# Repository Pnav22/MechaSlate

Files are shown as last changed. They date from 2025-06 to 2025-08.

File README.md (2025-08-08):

# MechaSlate 
**A Custom-Built Mechanical Keyboard**  
by Pranav M

---


## Overview
**MechaSlate** is my first custom mechanical keyboard project, created from scratch with no prior experience. This build taught me PCB design using KiCad, CAD modeling with Fusion 360, and the use of plugins and scripts to place keyswitches

[Watch on YouTube](https://www.youtube.com/shorts/u8ZRRqsj9ko)

I wanted to make this project so I could learn more about electronics and familiarize myself with more forms of engineering. It was really fun!
---


####  Initial Layout Planning
I decided on I wanted to make a keyboard like this 
Layout

#### PCB Design

| Schematic |  PCB |
|:--:|:--:|
| Schematics | Wiring |

#### Case Design 
Back and front case modeled for print.

| Back | Front |
|:--:|:--:|
| | Front |

Added a staggering Slot pattern for the back!

####  Final Case
Manually placed all keycaps and installed everything.



---

#### Assembly 

It uses **threaded heat-set inserts (M3 x 5mm x 4mm)** for secure mounting. These inserts are installed into the case.

The top and bottom halves of the keyboard are fastened together using **four M3 x 16mm socket head cap screws .


This project has a Gasket Mount 


| Item Name | Item Source | Quantity | Cost (USD w/ shipping) | Link |
|---|---|---|---|---|
| [Akko V3 Creamy Blue](https://www.amazon.com/Keyboard-Switch-Dustproof-Mechanical-Tactile-Switches/dp/B0C3H7PR1Z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) | Amazon | 80 | $30.98 | ✔️ |
| [PCB x5 (min quantity)]() | JLCPCB | – | $35.00 | ✔️ |
| [1N4148 Diodes](https://www.amazon.com/120Pcs-Rectifier-100Volt-Electronic-Silicon/dp/B0DN62QFYS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) | Amazon | 80 | $5.00 | ✔️ |
| [Durock V3 Stabilizers](https://www.amazon.com/DUROCK-Stabilizer-Innovative-Pre-clipped-Stabilizers/dp/B0CTHNZWN5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) | Amazon | 8 | $15.00 | ✔️ |
| [Heatset Inserts](https://www.amazon.com/Threaded-Inserts-Soldering-Printed-Materials/dp/B0D7M3LJDL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) | Amazon | 4 | $7.00 | ✔️ |
| [Nice_Nano_V2](https://www.amazon.com/AITRIP-Development-Bluetooth-Management-Module%EF%BC%8CNano/dp/B0DCZJKYL1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) | Amazon | 1 | $15.00 | ✔️ |
| [Keycaps](https://www.amazon.com/Keycaps-Doubleshot-Percent-Mechanical-Keyboard/dp/B0D1QVD55F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) | Amazon | 80 | $18.00 | ✔️ |

**Total Cost:** **$125.98**

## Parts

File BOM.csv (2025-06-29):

Bill of Materials / MechaSlate
Pranav Mukkara
6/25/25
Item Name | Item Source | Quantity | cost USD(w/ shipping) | Link
Akko V3 Creamy Blue | Amazon | 80 | 30.98 | https://www.amazon.com/Keyboard-Switch-Dustproof-Mechanical-Tactile-Switches/dp/B0C3H7PR1Z
PCB x5 (min quantity) | PCB WAY |  | 70
1N4148 Diodes | Amazon | 80 | 5 | https://www.amazon.com/120Pcs-Rectifier-100Volt-Electronic-Silicon/dp/B0DN62QFYS
Durock V3 Stabilizers | Amazon | 8 | 15 | https://www.amazon.com/DUROCK-Stabilizer-Innovative-Pre-clipped-Stabilizers/dp/B0CTHNZWN5
heatset inserts | Amazon | 4 | 7 | https://www.amazon.com/Threaded-Inserts-Soldering-Printed-Materials/dp/B0D7M3LJDL
Nice_Nano_V2 | Amazon | 1 | 15 | https://www.amazon.com/AITRIP-Development-Bluetooth-Management-Module%EF%BC%8CNano/dp/B0DCZJKYL1
keycaps | Amazon | 80 | 18 | https://www.amazon.com/Keycaps-Doubleshot-Percent-Mechanical-Keyboard/dp/B0D1QVD55F
Total: |  |  | 160.98

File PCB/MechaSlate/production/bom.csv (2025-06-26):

Designator | Footprint | Quantity | Value | LCSC Part #
D1, D10, D11, D12, D13, D14, D15, D16, D17, D18, D19, D2, D20, D21, D22, D23, D24, D25, D26, D27, D28, D29, D3, D30, D31, D32, D33, D34, D35, D36, D37, D38, D39, D4, D40, D41, D42, D43, D44, D45, D46, D47, D48, D49, D5, D50, D51, D52, D53, D54, D55, D56, D57, D58, D59, D6, D60, D61, D62, D63, D64, D65, D66, D67, D68, D69, D7, D70, D71, D72, D73, D74, D75, D76, D77, D78, D8, D9 | Diode_DO-35 | 78 | Diode
S1, S10, S11, S12, S13, S14, S15, S16, S17, S18, S19, S2, S20, S21, S22, S23, S24, S25, S26, S27, S28, S29, S3, S30, S31, S32, S33, S34, S35, S36, S37, S38, S39, S4, S40, S41, S42, S43, S44, S45, S46, S47, S48, S49, S5, S50, S51, S52, S53, S54, S55, S56, S57, S58, S59, S6, S60, S61, S62, S63, S64, S65, S66, S67, S68, S69, S7, S70, S71, S72, S73, S74, S75, S76, S77, S78, S8, S9 | SW_Cherry_MX_1.00u_PCB | 78 | Keyswitch
U2 | Nice_Nano_V2 | 1 | Nice_Nano_V2

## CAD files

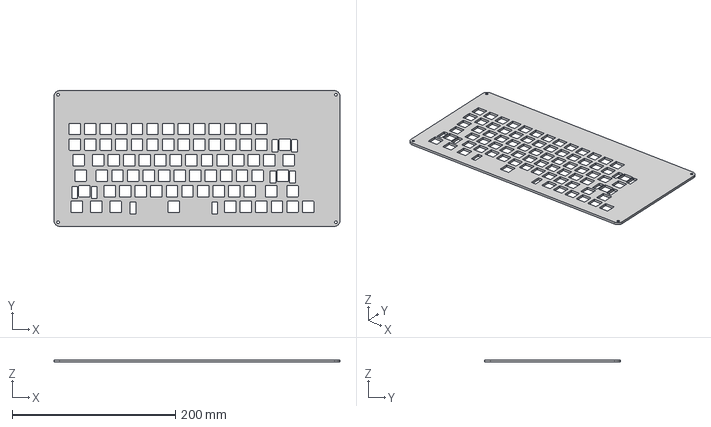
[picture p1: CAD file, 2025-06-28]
CAD/MIDDLE v4.step
350.2 x 166.2 x 3.00 mm

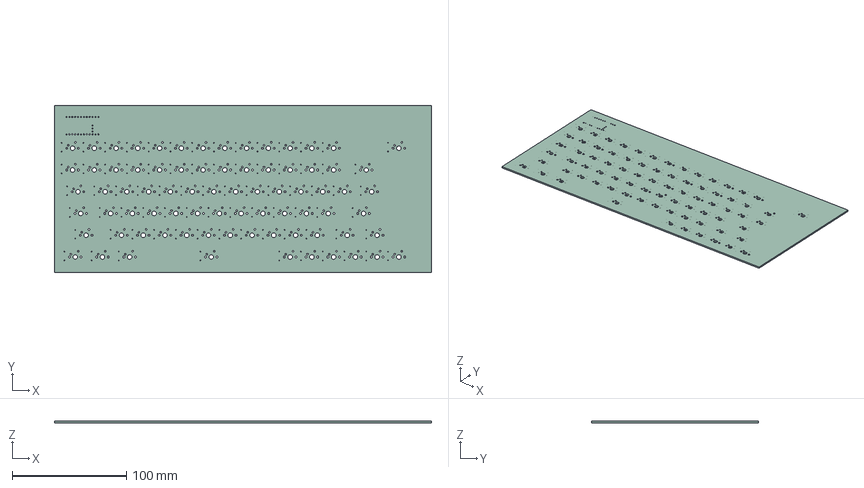
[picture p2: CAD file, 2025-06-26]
PCB/MechaSlate/MechaSlate.step
330.1 x 146.2 x 1.51 mm

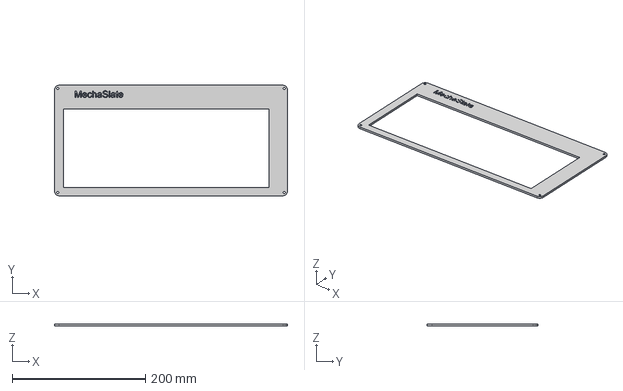
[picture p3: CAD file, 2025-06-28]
CAD/Top v6.step
350.2 x 166.2 x 3.00 mm

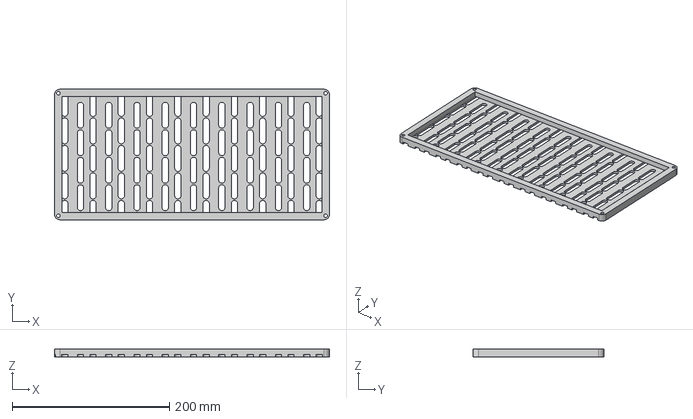
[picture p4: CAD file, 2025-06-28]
Production/Bottom v7.step
350.1 x 166.2 x 10.0 mm

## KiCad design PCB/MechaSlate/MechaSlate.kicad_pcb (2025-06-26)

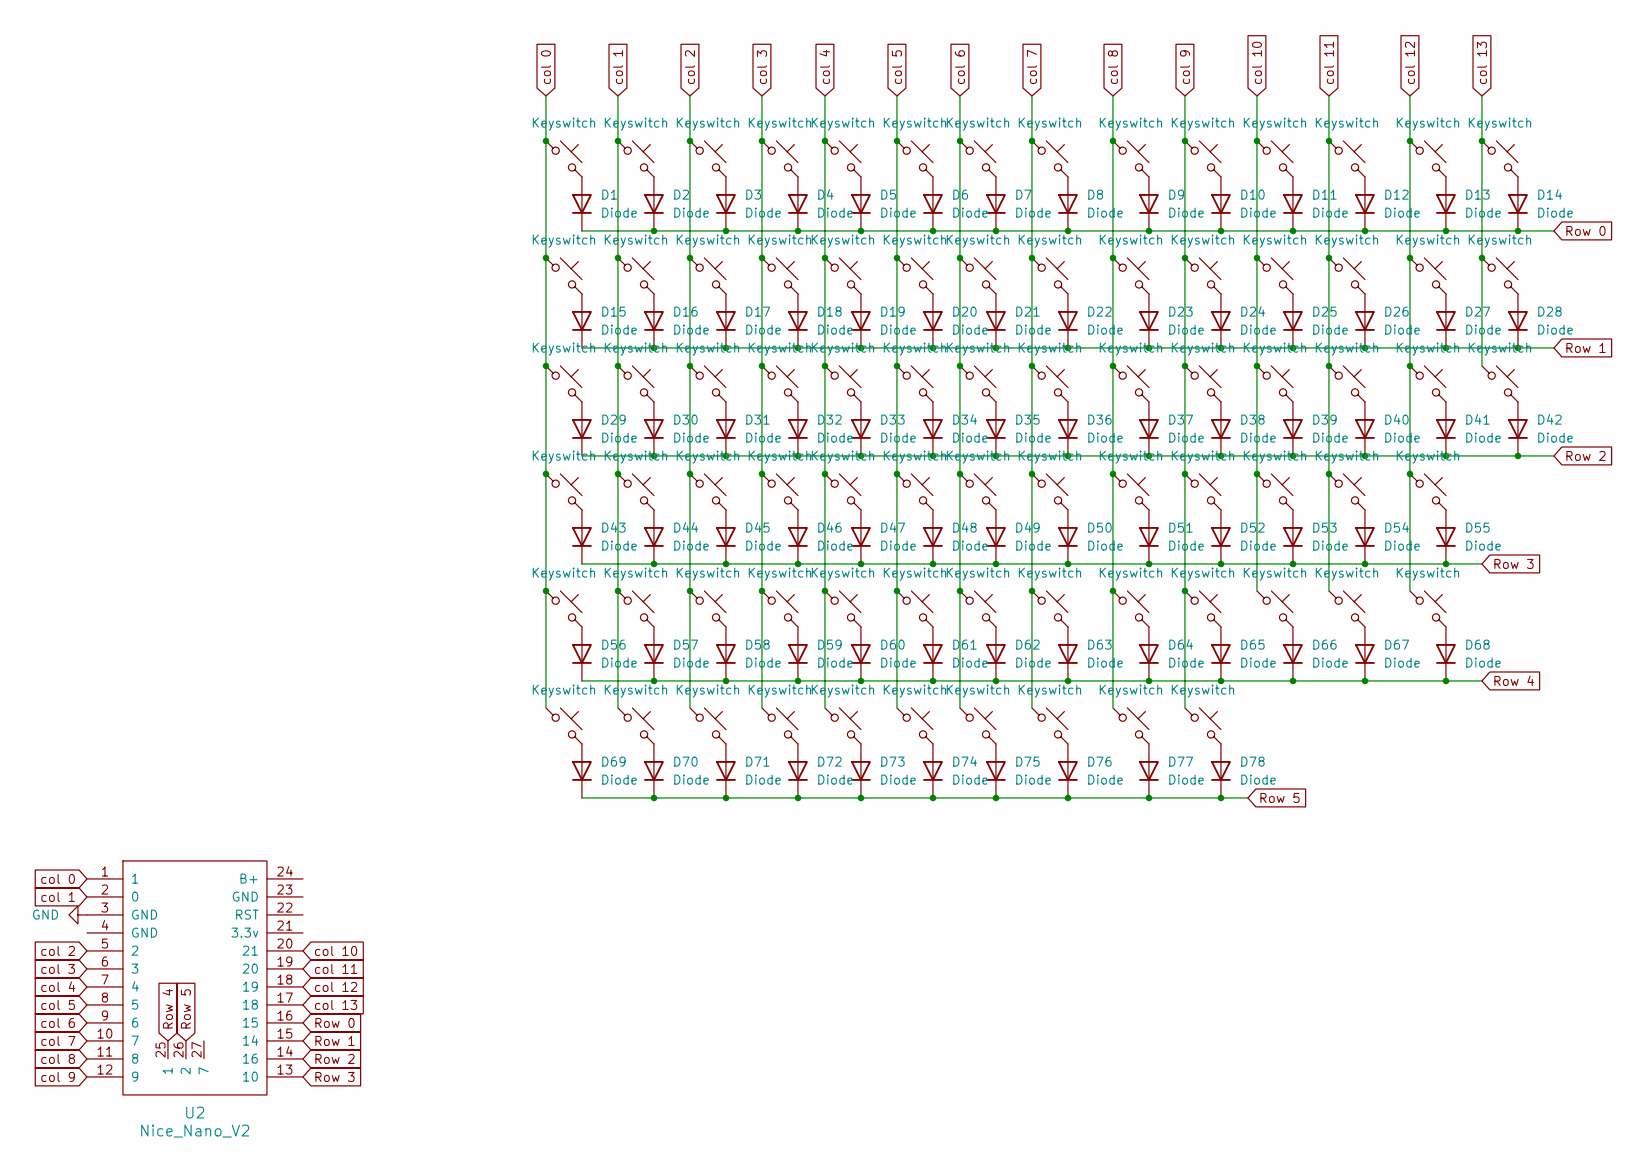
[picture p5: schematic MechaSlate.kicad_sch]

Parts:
D1, D2, D3, D4, D5, D6, D7, D8, D9, D10, D11, D12, D13, D14, D15, D16, D17, D18, D19, D20, D21, D22, D23, D24, D25, D26, D27, D28, D29, D30, D31, D32, D33, D34, D35, D36, D37, D38, D39, D40, D41, D42, D43, D44, D45, D46, D47, D48, D49, D50, D51, D52, D53, D54, D55, D56, D57, D58, D59, D60, D61, D62, D63, D64, D65, D66, D67, D68, D69, D70, D71, D72, D73, D74, D75, D76, D77, D78: Diode; Diode_DO-35
S1, S2, S3, S4, S5, S6, S7, S8, S9, S10, S11, S12, S13, S14, S15, S16, S17, S18, S19, S20, S21, S22, S23, S24, S25, S26, S27, S28, S29, S30, S31, S32, S33, S34, S35, S36, S37, S38, S39, S40, S41, S42, S43, S44, S45, S46, S47, S48, S49, S50, S51, S52, S53, S54, S55, S56, S57, S58, S59, S60, S61, S62, S63, S64, S65, S66, S67, S68, S69, S70, S71, S72, S73, S74, S75, S76, S77, S78: Keyswitch; SW_Cherry_MX_1.00u_PCB
U2: Nice_Nano_V2

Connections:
GND: U2.3 (GND)
unnamed: D1.2 (A), S1.2
unnamed: D2.2 (A), S2.2
unnamed: D3.2 (A), S3.2
unnamed: D4.2 (A), S4.2
unnamed: D5.2 (A), S5.2
unnamed: D6.2 (A), S6.2
unnamed: D7.2 (A), S7.2
unnamed: D8.2 (A), S8.2
unnamed: D9.2 (A), S9.2
unnamed: D10.2 (A), S10.2
unnamed: D11.2 (A), S11.2
unnamed: D12.2 (A), S12.2
unnamed: D13.2 (A), S13.2
unnamed: D14.2 (A), S14.2
unnamed: D15.2 (A), S15.2
unnamed: D16.2 (A), S16.2
unnamed: D17.2 (A), S17.2
unnamed: D18.2 (A), S18.2
unnamed: D19.2 (A), S19.2
unnamed: D20.2 (A), S20.2
unnamed: D21.2 (A), S21.2
unnamed: D22.2 (A), S22.2
unnamed: D23.2 (A), S23.2
unnamed: D24.2 (A), S24.2
unnamed: D25.2 (A), S25.2
unnamed: D26.2 (A), S26.2
unnamed: D27.2 (A), S27.2
unnamed: D28.2 (A), S28.2
unnamed: D29.2 (A), S29.2
unnamed: D30.2 (A), S30.2
unnamed: D31.2 (A), S31.2
unnamed: D32.2 (A), S32.2
unnamed: D33.2 (A), S33.2
unnamed: D34.2 (A), S34.2
unnamed: D35.2 (A), S35.2
unnamed: D36.2 (A), S36.2
unnamed: D37.2 (A), S37.2
unnamed: D38.2 (A), S38.2
unnamed: D39.2 (A), S39.2
unnamed: D40.2 (A), S40.2
unnamed: D41.2 (A), S41.2
unnamed: D42.2 (A), S42.2
unnamed: D43.2 (A), S43.2
unnamed: D44.2 (A), S44.2
unnamed: D45.2 (A), S45.2
unnamed: D46.2 (A), S46.2
unnamed: D47.2 (A), S47.2
unnamed: D48.2 (A), S48.2
unnamed: D49.2 (A), S49.2
unnamed: D50.2 (A), S50.2
unnamed: D51.2 (A), S51.2
unnamed: D52.2 (A), S52.2
unnamed: D53.2 (A), S53.2
unnamed: D54.2 (A), S54.2
unnamed: D55.2 (A), S55.2
unnamed: D56.2 (A), S56.2
unnamed: D57.2 (A), S57.2
unnamed: D58.2 (A), S58.2
unnamed: D59.2 (A), S59.2
unnamed: D60.2 (A), S60.2
unnamed: D61.2 (A), S61.2
unnamed: D62.2 (A), S62.2
unnamed: D63.2 (A), S63.2
unnamed: D64.2 (A), S64.2
unnamed: D65.2 (A), S65.2
unnamed: D66.2 (A), S66.2
unnamed: D67.2 (A), S67.2
unnamed: D68.2 (A), S68.2
unnamed: D69.2 (A), S69.2
unnamed: D70.2 (A), S70.2
unnamed: D71.2 (A), S71.2
unnamed: D72.2 (A), S72.2
unnamed: D73.2 (A), S73.2
unnamed: D74.2 (A), S74.2
unnamed: D75.2 (A), S75.2
unnamed: D76.2 (A), S76.2
unnamed: D77.2 (A), S77.2
unnamed: D78.2 (A), S78.2
Row 0: D1.1 (K), D2.1 (K), D3.1 (K), D4.1 (K), D5.1 (K), D6.1 (K), D7.1 (K), D8.1 (K), D9.1 (K), D10.1 (K), D11.1 (K), D12.1 (K), D13.1 (K), D14.1 (K), U2.16 (15)
Row 1: D15.1 (K), D16.1 (K), D17.1 (K), D18.1 (K), D19.1 (K), D20.1 (K), D21.1 (K), D22.1 (K), D23.1 (K), D24.1 (K), D25.1 (K), D26.1 (K), D27.1 (K), D28.1 (K), U2.15 (14)
Row 2: D29.1 (K), D30.1 (K), D31.1 (K), D32.1 (K), D33.1 (K), D34.1 (K), D35.1 (K), D36.1 (K), D37.1 (K), D38.1 (K), D39.1 (K), D40.1 (K), D41.1 (K), D42.1 (K), U2.14 (16)
Row 3: D43.1 (K), D44.1 (K), D45.1 (K), D46.1 (K), D47.1 (K), D48.1 (K), D49.1 (K), D50.1 (K), D51.1 (K), D52.1 (K), D53.1 (K), D54.1 (K), D55.1 (K), U2.13 (10)
Row 4: D56.1 (K), D57.1 (K), D58.1 (K), D59.1 (K), D60.1 (K), D61.1 (K), D62.1 (K), D63.1 (K), D64.1 (K), D65.1 (K), D66.1 (K), D67.1 (K), D68.1 (K), U2.25 (1)
Row 5: D69.1 (K), D70.1 (K), D71.1 (K), D72.1 (K), D73.1 (K), D74.1 (K), D75.1 (K), D76.1 (K), D77.1 (K), D78.1 (K), U2.26 (2)
col 0: S1.1, S15.1, S29.1, S43.1, S56.1, S69.1, U2.1
col 1: S2.1, S16.1, S30.1, S44.1, S57.1, S70.1, U2.2 (0)
col 2: S3.1, S17.1, S31.1, S45.1, S58.1, S71.1, U2.5 (2)
col 3: S4.1, S18.1, S32.1, S46.1, S59.1, S72.1, U2.6 (3)
col 4: S5.1, S19.1, S33.1, S47.1, S60.1, S73.1, U2.7 (4)
col 5: S6.1, S20.1, S34.1, S48.1, S61.1, S74.1, U2.8 (5)
col 6: S7.1, S21.1, S35.1, S49.1, S62.1, S75.1, U2.9 (6)
col 7: S8.1, S22.1, S36.1, S50.1, S63.1, S76.1, U2.10 (7)
col 8: S9.1, S23.1, S37.1, S51.1, S64.1, S77.1, U2.11 (8)
col 9: S10.1, S24.1, S38.1, S52.1, S65.1, S78.1, U2.12 (9)
col 10: S11.1, S25.1, S39.1, S53.1, S66.1, U2.20 (21)
col 11: S12.1, S26.1, S40.1, S54.1, S67.1, U2.19 (20)
col 12: S13.1, S27.1, S41.1, S55.1, S68.1, U2.18 (19)
col 13: S14.1, S28.1, S42.1, U2.17 (18)

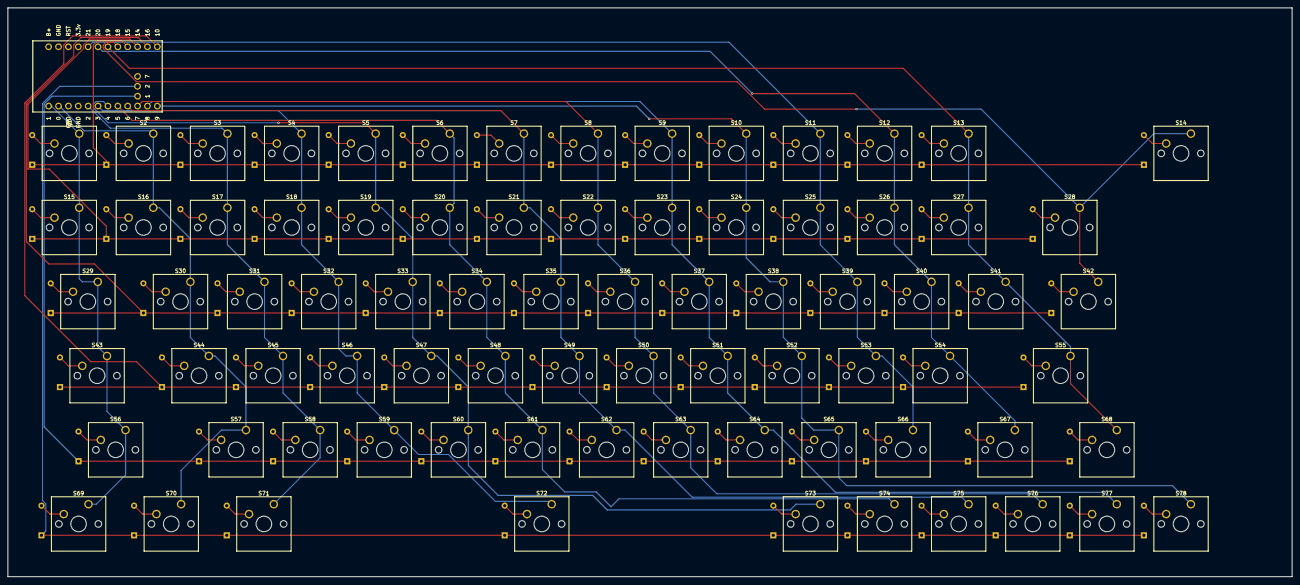
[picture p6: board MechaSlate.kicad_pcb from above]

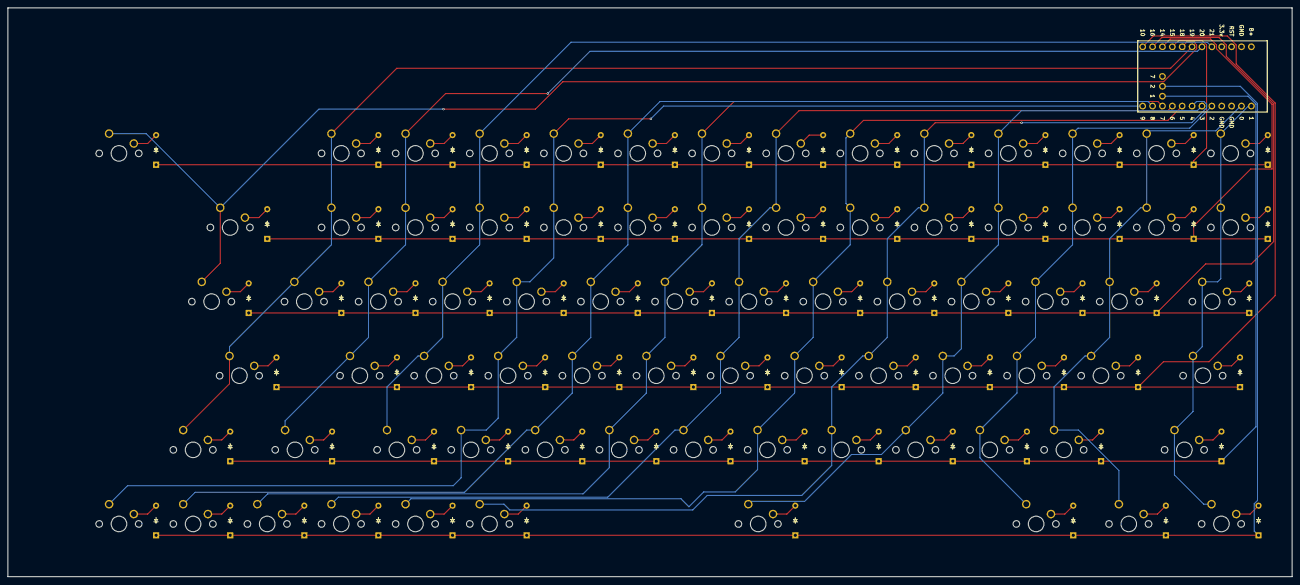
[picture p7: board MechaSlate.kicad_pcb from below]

Board: 2 copper layers, 330.1 x 146.2 mm, 157 parts (78 on the bottom side), 98 nets.

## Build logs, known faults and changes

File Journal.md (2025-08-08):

---
title: "Mecha Slate"
author: "Pranav Mukkara"
description: "Custom Built Keyboard"
created_at: "2025-06-20"
---

**Total Time Spent: 1080 minutes (18 hours)**

---

## June 20: Research, Learning, and Starting

So this is my first time making a keyboard. I had zero experience. I first learned how to make some basic PCBs on KiCad following Joe Scotto's tutorial. Very nice guy!  
Link here: https://www.youtube.com/watch?v=8WXpGTIbxlQ&ab_channel=JoeScotto  
Here is some sample circuits I made from his tutorial.

**Total Time Spent: 60 mins**

### created practice PCBs  
| PCB | Schematic |
|:---:|:---:|
| PCB Front | PCB Back |

**Total Time Spent: 90 mins**

---

## June 21: Initial Design

This was kinda scary because I was so afraid of messing something up. I knew I wanted a keyboard with  no number pad. Here is a reference:



I made an initial sketch for the matrix. I decided to use the Arduino Pro Micro for my MCU.



Decide to base my project off this keyboard: 


_Edit: I'm not doing the top row – the ESC row._  

I dont know how mechanical keyboards work so I did a little research on this stuff. Apparently it doesnt seem so hard to make? I think I could make this easily. 
_Edit: This was so hard. It is so so hard to engineer stuff :( But I kinda like the struggle _


**Total Time Spent: 60 mins**

---

## June 21: Making the Schematics
_Edit: I decided to do the esc row again _

So I made this schematic. I used a json file and free tool online to make it. It was convient and it gave me this. 

So far so good lets move on.
**Total Time Spent: 30 mins**

## June 21: Making the pcb
Disaster struck. For some reason the schematic was so buns I could barely make the pcb. The schematic was missing things and their were just a whole bunch of errors. 


I spent like a hour trying to troubleshoot. I installed, reinstalled, i did all the librarys again and i searched online. Massive waste of time.

**Total Time Spent: 90 mins**

## June 22: Restarting
So I made so many mistakes and everything that i thought it would be easier to just restart from scratch. 
So i delted everything - very painfull 
and redid the schematic. 



Was very painful to do this again. BUT LOOK. SO PRETTY

Something I learned is that you should keep everything bevel and straight. When I duplicated the switches they would shift down slightly or up. this made wiring so hard I decided to wipe and create a schematic where everything was on the same level so i could wire with straight lines. - something to learn for the future. 

**Total Time Spent: 60 mins**

---

## June 21: Remaking the PCB

I didn’t want to manually move each square, so I’m trying to find a better solution—probably a plugin.  
Found a plugin to use. It was an absolute pain to use.  
Used a JSON file.  
This is hopefully what it should look like perfect:

This is the most painful thing I have done so far. The wiring was an absolute pain in the butt.



So much better than the last PCB
but look its so pretty. I added a angry face to it aswl. I really like how it turned out. 

Most of this time was spent on trying to use the plugin. 
**Time Spent: 180 mins**
---

## June 25: Making the CAD

This should be the easiest part.

**Back done**  


**Front done**  


Now just assembly.  

Finally finished the whole project. Manually putting the keycaps in took very long.



It took so long because I manually inserted and moved every switch and key. Not a good idea for the future. 
**Time Spent: 240 mins**

## June 28: updated the case

Added a staggering slot pattern to the case to save more filament. 

Before:


After 



**Time Spent: 30 mins**

## June 28: Added a outer shell - gasket mound

Added a gasket mount for more stability


Before: 


After:


**Time Spent: 60 mins**

## August 7: IRL build!

WhatsApp Image 2025-08-08 at 10 25 01_2bf22ea1
WhatsApp Image 2025-08-08 at 10 24 31_b3d29708
WhatsApp Image 2025-08-08 at 10 24 10_54df2d22
WhatsApp Image 2025-08-07 at 19 25 03_bbce36dc

**Time Spent:  180 mins**

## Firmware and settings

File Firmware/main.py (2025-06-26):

import board
from kmk.kmk_keyboard import KMKKeyboard
from kmk.scanners import DiodeOrientation

from kmk.keys import KC
from kmk.modules.layers import Layers

keyboard = KMKKeyboard()

keyboard.modules.append(Layers())

keyboard.col_pins = (
    board.D2, board.D3, board.D4, board.D5, board.D6,
    board.D7, board.D8, board.D9, board.D10, board.D11,
    board.D12, board.D13, board.D14, board.D15, board.D16,
)

keyboard.row_pins = (
    board.D20, board.D19, board.D18,
    board.D17, board.D22, board.D21,
)

keyboard.diode_orientation = DiodeOrientation.COL2ROW

keyboard.keymap = [
    [  
        KC.ESC, KC.F1, KC.F2, KC.F3, KC.F4, KC.F5, KC.F6, KC.F7, KC.F8, KC.F9, KC.F10, KC.F11, KC.F12, KC.NO, KC.DEL,
        KC.GRV, KC._1, KC._2, KC._3, KC._4, KC._5, KC._6, KC._7, KC._8, KC._9, KC._0, KC.MINS, KC.EQL, KC.BSPC, KC.INS,
        KC.TAB, KC.Q, KC.W, KC.E, KC.R, KC.T, KC.Y, KC.U, KC.I, KC.O, KC.P, KC.LBRC, KC.RBRC, KC.BSLS, KC.HOME,
        KC.CAPS, KC.A, KC.S, KC.D, KC.F, KC.G, KC.H, KC.J, KC.K, KC.L, KC.SCLN, KC.QUOT, KC.ENT, KC.NO, KC.PGUP,
        KC.LSFT, KC.Z, KC.X, KC.C, KC.V, KC.B, KC.N, KC.M, KC.COMM, KC.DOT, KC.SLSH, KC.RSFT, KC.UP, KC.PGDN, KC.NO,
        KC.LCTL, KC.LGUI, KC.LALT, KC.SPC, KC.SPC, KC.RALT, KC.RGUI, KC.MENU, KC.RCTL, KC.LEFT, KC.DOWN, KC.RGHT, KC.NO, KC.NO, KC.NO,
    ]
]

if __name__ == '__main__':
    keyboard.go()

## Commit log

2025-06-26 Update and rename BOM - Sheet1.csv to BOM.csv
    [BOM.csv]
2025-06-26 Added stuff
    [Bottom v6.step, Top v3.step]
2025-06-26 added pcb
    [MechaSlate.kicad_sch]
2025-06-26 added source files pcb
    [MechaSlate-B_Cu.gbr, MechaSlate-B_Mask.gbr, MechaSlate-B_Paste.gbr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]
2025-06-28 Create Bottom v1.step
    [Bottom v1.step]
2025-06-28 More changes to CAD
    [Bottom v6.step, Bottom v7.step]
2025-06-28 Changed Cad
    [Bottom v6.step, Bottom v7.step]
